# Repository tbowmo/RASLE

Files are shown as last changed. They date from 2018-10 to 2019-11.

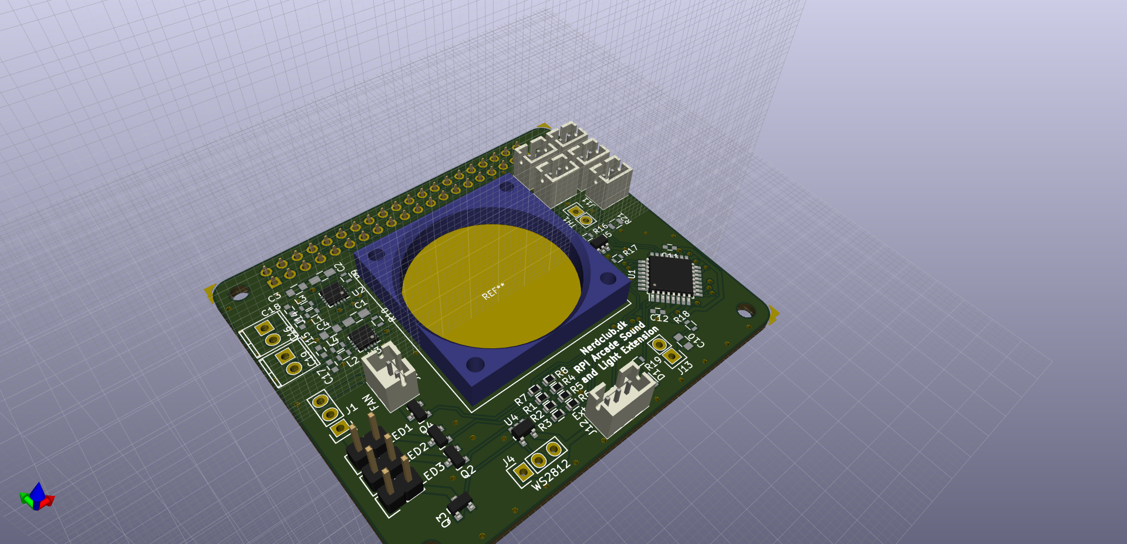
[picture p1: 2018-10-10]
concept.png

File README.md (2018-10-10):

### NerdClub RASLE board (Rpi Arcade Sound and Light Extension)

This board is an extension board for an arcade cabinet build by the members of Nerdclub.dk, main reason is to be able to make propper shutdown of the arcade cabinet / rpi, and for making easy light control during startup / shutdown sequences.

Features of the board:
* Atmega328 for controlling the board, with the following "peripherals"
 * 3 x 12V PWM channels for LED strips
 * 1 x 5V PWM channel for the onboard FAN
 * header for WS2812B strip (including level converter from 3v3 to 5v)
 * Port for external relay board (for switching mains power)
 * 1 button input routed to the atmeaga328
* RaspberryPI connected things
 * 4 button inputs routed directly to the RPI GPIO header
 * stereo channel I2S 3W class D amplifier (2 x MAX98357)
 * I2C HAT eeprom for configuration

Atmega <-> RPI connections:
* Standard serial port
* SPI / ISP (rpi can reprogram the atmega directly via GPIO)
* I2C HAT eeprom (you could emulate RPI HAT eeprom in the atmega if wanted)
* Reset signal from RPI -> ATmega (disabled via jumper)

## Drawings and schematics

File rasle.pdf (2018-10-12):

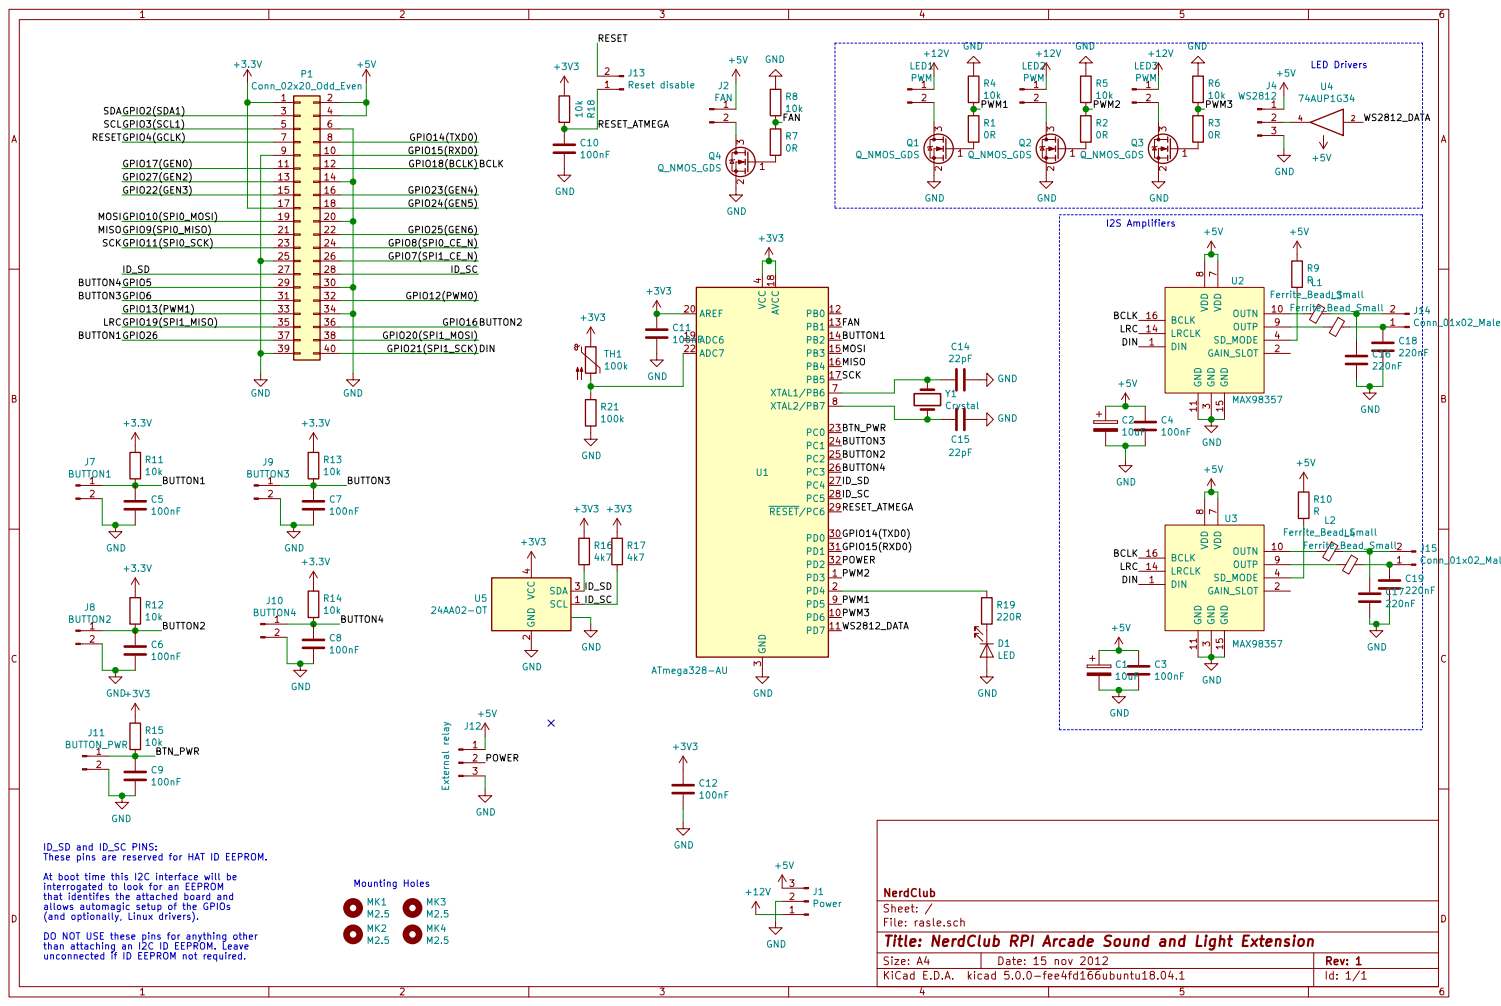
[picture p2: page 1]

SCK MISO MOSI FAN GND

8 OUTP 9 U2MAX98357 DIN 1 OUTN 10 GND 11

ID_SD and ID_SC PINS: These pins are reserved for HAT ID EEPROM. At boot time this I2C interface will be

interrogated to look for an EEPROM
that identifes the attached board and
allows automagic setup of the GPIOs
(and optionally, Linux drivers).
DO NOT USE these pins for anything other
than attaching an I2C ID EEPROM. Leave

File: rasle.sch Sheet: / NerdClub

Id: 1/1 Title: NerdClub RPI Arcade Sound and Light Extension

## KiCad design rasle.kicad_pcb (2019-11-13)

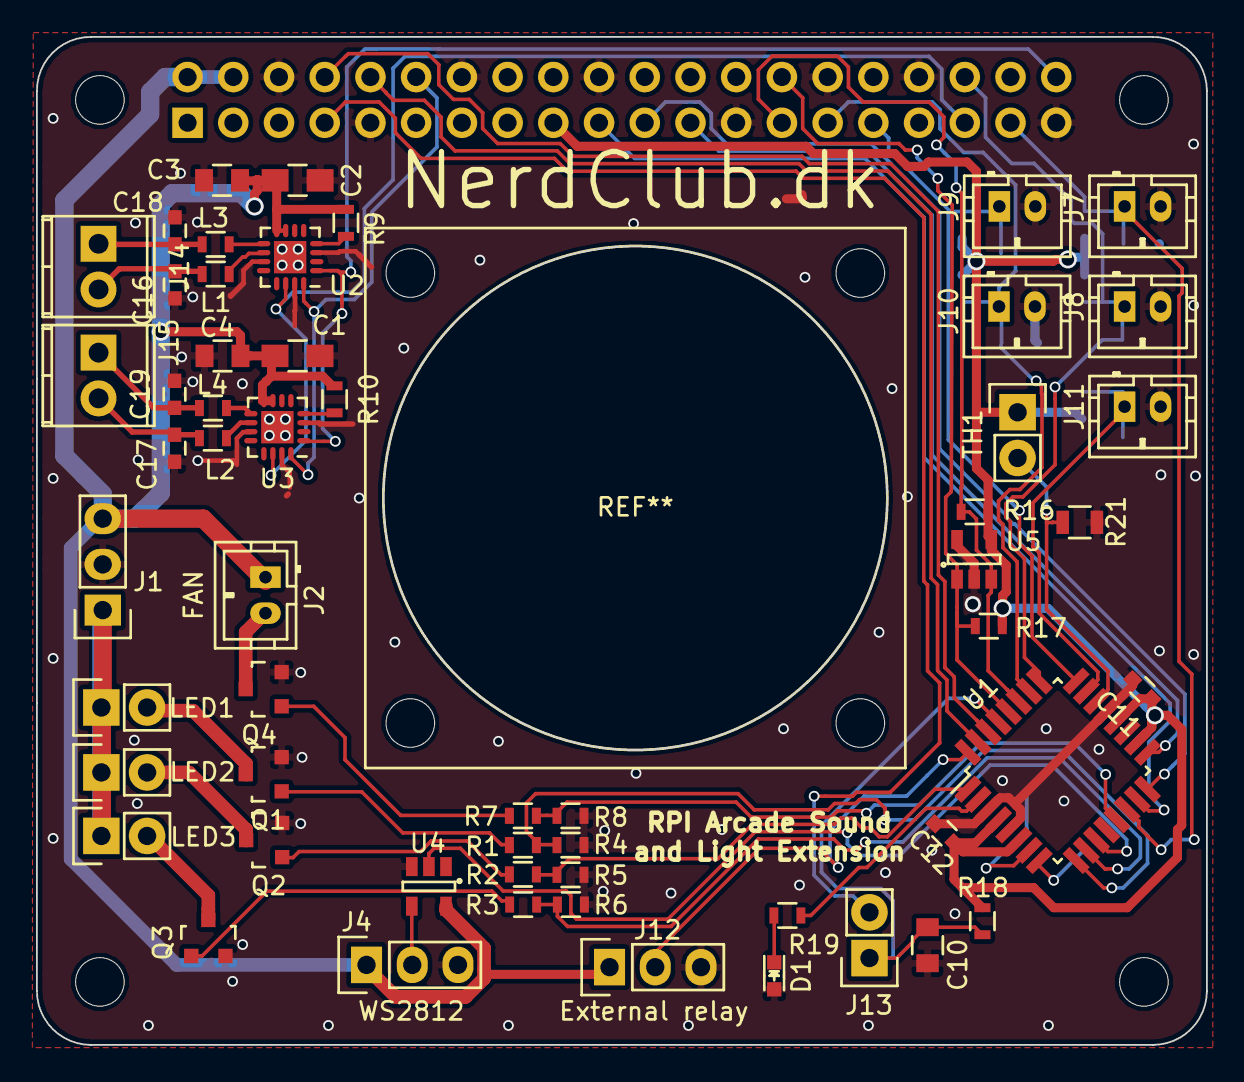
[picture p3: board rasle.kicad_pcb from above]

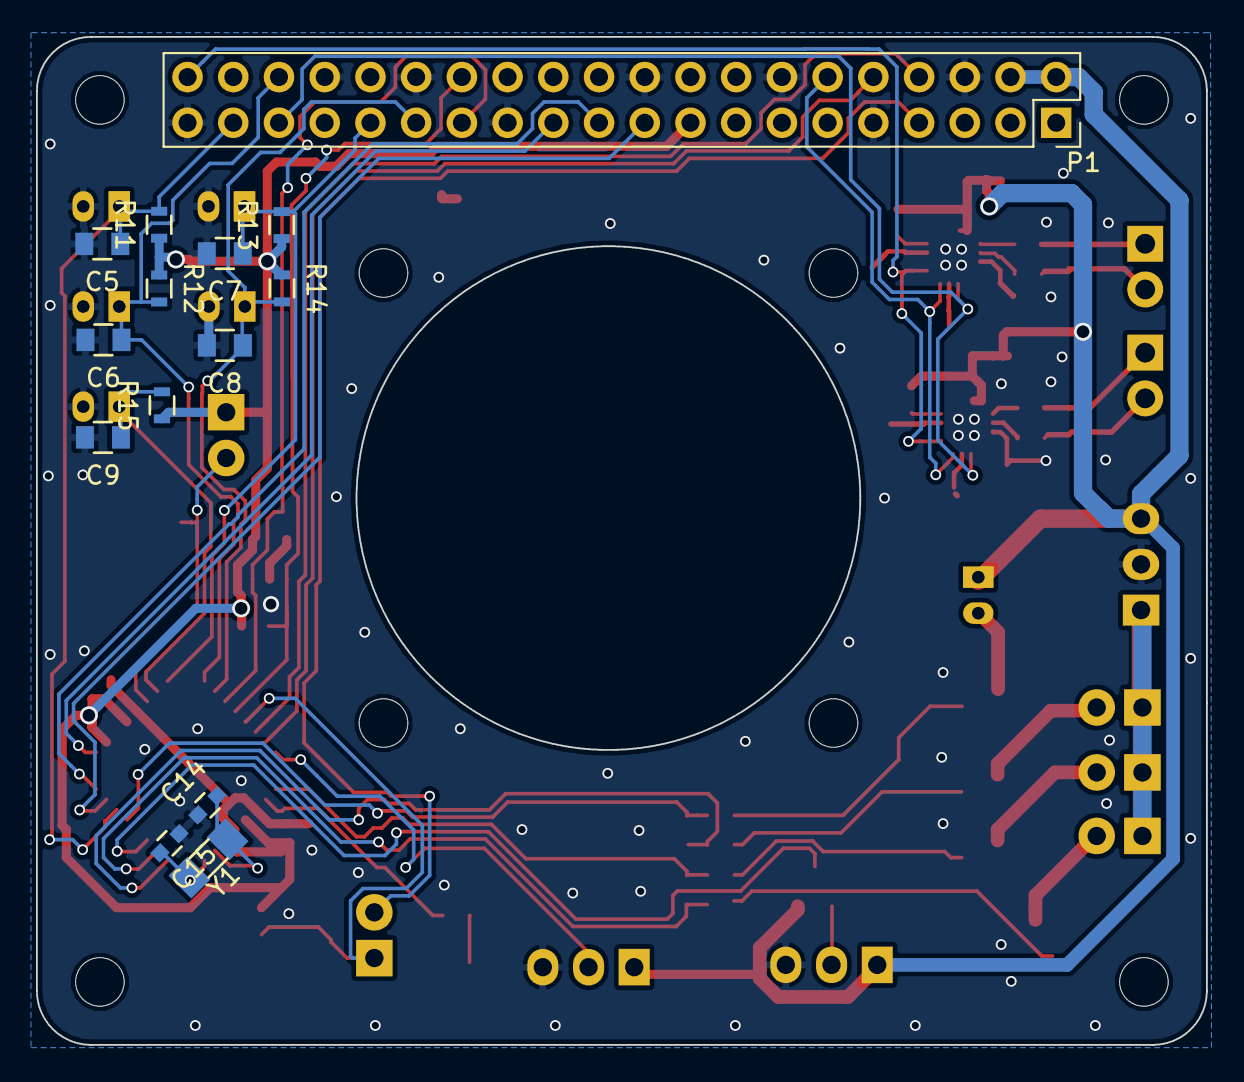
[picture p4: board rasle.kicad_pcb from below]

Board: 2 copper layers, 65.0 x 56.0 mm, 74 parts (14 on the bottom side), 51 nets.

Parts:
C1, C2: 10uF; C_0805_HandSoldering
C3, C4, C5, C6, C7, C8, C9, C10: 100nF; C_0805
C11, C12: 100nF; C_0603
C14, C15: 22pF; C_0603
C16, C17, C18, C19: 220nF; C_0603
D1: LED; LED-0603
J1: Power; Pin_Header_Straight_1x03
J2: FAN; Connectors_JST_B2B-PH-K
J4: WS2812; Pin_Header_Straight_1x03
J7: BUTTON1; Connectors_JST_B2B-PH-K
J8: BUTTON2; Connectors_JST_B2B-PH-K
J9: BUTTON3; Connectors_JST_B2B-PH-K
J10: BUTTON4; Connectors_JST_B2B-PH-K
J11: BUTTON_PWR; Connectors_JST_B2B-PH-K
J12: External relay; Pin_Header_Straight_1x03
J13: Reset disable; Pin_Header_Straight_1x02
J14, J15: Conn_01x02_Male; TerminalBlock_Pheonix_MPT-2.54mm_2pol
L1, L2, L3, L4: Ferrite_Bead_Small; R_0603
LED1, LED2, LED3: PWM; Pin_Header_Straight_1x02
MK1, MK2, MK3, MK4: M2.5; MountingHole_2.7mm_M2.5
P1: Conn_02x20_Odd_Even; PinSocket_2x20_P2.54mm_Vertical
Q1, Q2, Q3, Q4: Q_NMOS_GDS; SOT-23
R1, R2, R3, R7: 0R; R_0603
R4, R5, R6, R8, R11, R12, R13, R14, R15, R18: 10k; R_0603
R9, R10: R; R_0603
R16, R17: 4k7; R_0603
R19: 220R; R_0603
R21: 100k; R_0805
TH1: 100k; Pin_Header_Straight_1x02
U1: ATmega328-AU; TQFP-32_7x7mm_Pitch0.8mm
U2, U3: MAX98357; QFN-16-1EP_3x3mm_Pitch0.5mm
U4: 74AUP1G34; SOT-23-5
U5: 24AA02-OT; SOT-23-5
Y1: Crystal; XTAL_3.2x1.5mm

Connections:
+3V3: C11.1, C12.1, P1.1, P1.17, R11.1, R12.1, R13.1, R14.1, R15.1, R16.1, R17.1, R18.2, TH1.1, U1.4, U1.6, U1.18, U1.20, U5.4
+5V: C1.1, C2.1, C3.1, C4.1, J1.3, J2.1, J4.1, J12.1, P1.2, P1.4, R9.1, R10.1, U2.7, U2.8, U3.7, U3.8, U4.5
+12V: J1.1, LED1.1, LED2.1, LED3.1
/BCLK: P1.12, U2.16, U3.16
/BTN_PWR: C9.1, J11.1, R15.2, U1.23
/BUTTON1: C5.1, J7.1, P1.37, R11.2, U1.14
/BUTTON2: C6.1, J8.1, P1.36, R12.2, U1.25
/BUTTON3: C7.1, J9.1, P1.31, R13.2, U1.24
/BUTTON4: C8.1, J10.1, P1.29, R14.2, U1.26
/DIN: P1.40, U2.1, U3.1
/FAN: R7.1, R8.2, U1.13
/GPIO4(GCLK): J13.2, P1.7
/GPIO9(SPI0_MISO): P1.21, U1.16
/GPIO10(SPI0_MOSI): P1.19, U1.15
/GPIO11(SPI0_SCK): P1.23, U1.17
/GPIO14(TXD0): P1.8, U1.30
/GPIO15(RXD0): P1.10, U1.31
/GPIO19(SPI1_MISO): P1.35, U2.14, U3.14
/ID_SC: P1.28, R17.2, U1.28, U5.1
/ID_SD: P1.27, R16.2, U1.27, U5.3
/POWER: J12.2, U1.32
/PWM1: R1.1, R4.2, U1.9
/PWM2: R2.1, R5.2, U1.1
/PWM3: R3.1, R6.2, U1.10
/RESET_ATMEGA: C10.1, J13.1, R18.1, U1.29
/WS2812_DATA: U1.11, U4.2
GND: C1.2, C2.2, C3.2, C4.2, C5.2, C6.2, C7.2, C8.2, C9.2, C10.2, C11.2, C12.2, C14.1, C15.1, C16.2, C17.2, C18.2, C19.2, D1.2, J1.2, J4.3, J7.2, J8.2, J9.2, J10.2, J11.2, J12.3, P1.6, P1.9, P1.14, P1.20, P1.25, P1.30, P1.34, P1.39, Q1.2, Q2.2, Q3.2, Q4.2, R4.1, R5.1, R6.1, R8.1, R21.2, U1.3, U1.5, U1.21, U2.3, U2.11, U2.15, U2.17, U3.3, U3.11, U3.15, U3.17, U4.3, U5.2, U5.5
unnamed: C14.2, U1.7, Y1.1
unnamed: C15.2, U1.8, Y1.2
unnamed: C16.1, J14.2, L1.1
unnamed: C17.1, J15.2, L2.1
unnamed: C18.1, J14.1, L3.1
unnamed: C19.1, J15.1, L4.1
unnamed: D1.1, R19.2
unnamed: J2.2, Q4.3
unnamed: J4.2, U4.4
unnamed: L1.2, U2.10
unnamed: L2.2, U3.10
unnamed: L3.2, U2.9
unnamed: L4.2, U3.9
unnamed: LED1.2, Q1.3
unnamed: LED2.2, Q2.3
unnamed: LED3.2, Q3.3
unnamed: Q1.1, R1.2
unnamed: Q2.1, R2.2
unnamed: Q3.1, R3.2
unnamed: Q4.1, R7.2
unnamed: R9.2, U2.4
unnamed: R10.2, U3.4
unnamed: R19.1, U1.2
unnamed: R21.1, TH1.2, U1.22

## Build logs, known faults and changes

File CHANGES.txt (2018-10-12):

commit 5de6ecbaa782078d122991c539d17ed5ec99d668
Author: Thomas Mørch <thomas-nospam@bowmo.dk>
Date:   Fri Oct 12 18:41:39 2018 +0200

    Connected atmega to all buttons, so it can listen to the same button events as RPI

commit 67c2c405f7b93c13a77c293ebc34dc6e7657874b
Author: Thomas Mørch <thomas-nospam@bowmo.dk>
Date:   Thu Oct 11 08:49:13 2018 +0200

    Minor touchup / beautifying of routing

commit 0f19d415ff7bd9cd38268dfc6717e46211871d13
Author: Thomas Mørch <thomas-nospam@bowmo.dk>
Date:   Wed Oct 10 22:19:56 2018 +0200

    Updated gerbers

commit b1856b7578f23b33af38089a7e51f424bab4d4e3
Author: Thomas Mørch <thomas-nospam@bowmo.dk>
Date:   Wed Oct 10 22:16:45 2018 +0200

    Removed RTC chip as it is not necessary

commit c9a923ccb87e92b1a1abff819b905fc5d8e45c46
Author: Thomas Mørch <thomas-nospam@bowmo.dk>
Date:   Mon Oct 8 20:35:05 2018 +0200

    Added RTC chip for timekeeping

commit bc97a11311349ed1eb7305a55c62c93d522068f3
Author: Thomas Mørch <thomas-nospam@bowmo.dk>
Date:   Sun Oct 7 00:07:07 2018 +0200

    Added EEPROM for HAT compatability

commit 2c33cad61d8b0cdc935c86e44fc5256f6e992214
Author: Thomas Mørch <thomas-nospam@bowmo.dk>
Date:   Fri Oct 5 22:01:37 2018 +0200

    added license files

commit 97bfdfae289123b831147d680f8bf33bf07cc314
Author: Thomas Mørch <thomas-nospam@bowmo.dk>
Date:   Fri Oct 5 21:57:52 2018 +0200

    Added manufacturing files

commit 4a774a55ad01dd46e42a50856435d59aecc850c2
Author: Thomas Mørch <thomas-nospam@bowmo.dk>
Date:   Thu Oct 4 21:56:09 2018 +0200

    Initial commit

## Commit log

2018-10-05 Added manufacturing files
    [rasle.kicad_pcb, rasle.sch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]
2018-10-06 Added EEPROM for HAT compatability
    [rasle.kicad_pcb, rasle.sch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]
2018-10-08 Added RTC chip for timekeeping
    [rasle.kicad_pcb, rasle.sch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]
2018-10-10 Removed RTC chip as it is not necessary
    [rasle.kicad_pcb, rasle.sch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]
2018-10-10 Updated gerbers
    [rasle-B.Cu.gbl, rasle-B.SilkS.gbo, rasle-Edge.Cuts.gm1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]
2018-10-11 Minor touchup / beautifying of routing
    [rasle-B.Cu.gbl, rasle-B.SilkS.gbo, rasle-Edge.Cuts.gm1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]
2018-10-12 Connected atmega to all buttons, so it can listen to the same button events as RPI
    [rasle-B.Cu.gbl, rasle-B.SilkS.gbo, rasle-Edge.Cuts.gm1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]
2019-11-13 PCB manufacturing
    [rasle-B.Cu.gbl, rasle-B_Cu.gbl, rasle-B_Mask.gbs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]
